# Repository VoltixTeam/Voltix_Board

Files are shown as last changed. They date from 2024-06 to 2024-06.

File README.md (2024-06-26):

# Voltix Board Hardware Design Files



The Voltix board is a development board for battery-free wireless devices. The on-board wireless microcontroller runs off energy harvested from, for example, a solar panel and uses only tiny capacitors as energy storage. For uploading new software, the board can be connected to a PC via USB. During sotware upload and debugging, the microcontroller is powered with a fixed supply voltage from USB. After programming, the board automatically switches over to untethered, battery-free operation.

Latest design files:
 - [Schematics](https://voltix-docs.vercel.app/artifacts/board/latest/schematics.pdf)
 - [Layout](https://voltix-docs.vercel.app/artifacts/board/latest/pcb.pdf)
 - [Assembly plan](https://voltix-docs.vercel.app/artifacts/board/latest/assembly.pdf)
 - [3D rendering](https://voltix-docs.vercel.app/artifacts/board/latest/3drendering.png)

## Specification

3D rendering

Essentially, the Voltix board combines a [Voltix probe](https://github.com/VoltixTeam/Voltix_ProbeHardware) and a Voltix module on a single board. The board has two 0.1" pin sockets that expose all relevant signals from the battery-free device, including 10 GPIOs that can be flexibly used for I2C, SPI or for reading analog sensors. These headers are also used to connect voltix shields to build fully featured devices without having to design custom PCBs. The board comes with a push button, an LED and a connector for a solar panel.

Specification:
 - 56mm x 23mm board with two expansion headers for shields
 - Boost converter with software-defined maximum power point tracking and energy measurement
 - 66uF on-board capacitance
 - 2V regulated output voltage
 - 64 MHz ARM Cortex-M4 MCU with integrated 2.4GHz radio
 - 128kB non-volatile FRAM to retain appliccation state across power outages
 - Ultra-low power RTC with power management functionality
 - Capacitor voltage sensing and ultra low power comparator with software-controlled thresholds
 - USB-C connector
 - CMSIS-DAP compatible: Supports programming via pyOCD and OpenOCD
 - Makes UART output from battery-free device available via USB
 - Push button and User LED

## Firmware

The board has a dedicated controller (Raspberry Pi RP2040) that manages the upload of new firmware and the communication with a PC. This controller is powered from USB whenever the board is connected to a PC. The software running on the controller is the same as on the [Voltix probe](https://github.com/VoltixTeam/Voltix_ProbeHardware) and can be found in [this repository](https://github.com/VoltixTeam/Voltix_ProbeSoftware). To upgrade the firmware on the controller, connect a wire from one of the ground pins to the test pad labelled 'USB_BOOT' on the bottom of the board, while plugging in the USB cable. A removable storage drive should appear on your PC. Drop a UF2 compatible binary into the drive.

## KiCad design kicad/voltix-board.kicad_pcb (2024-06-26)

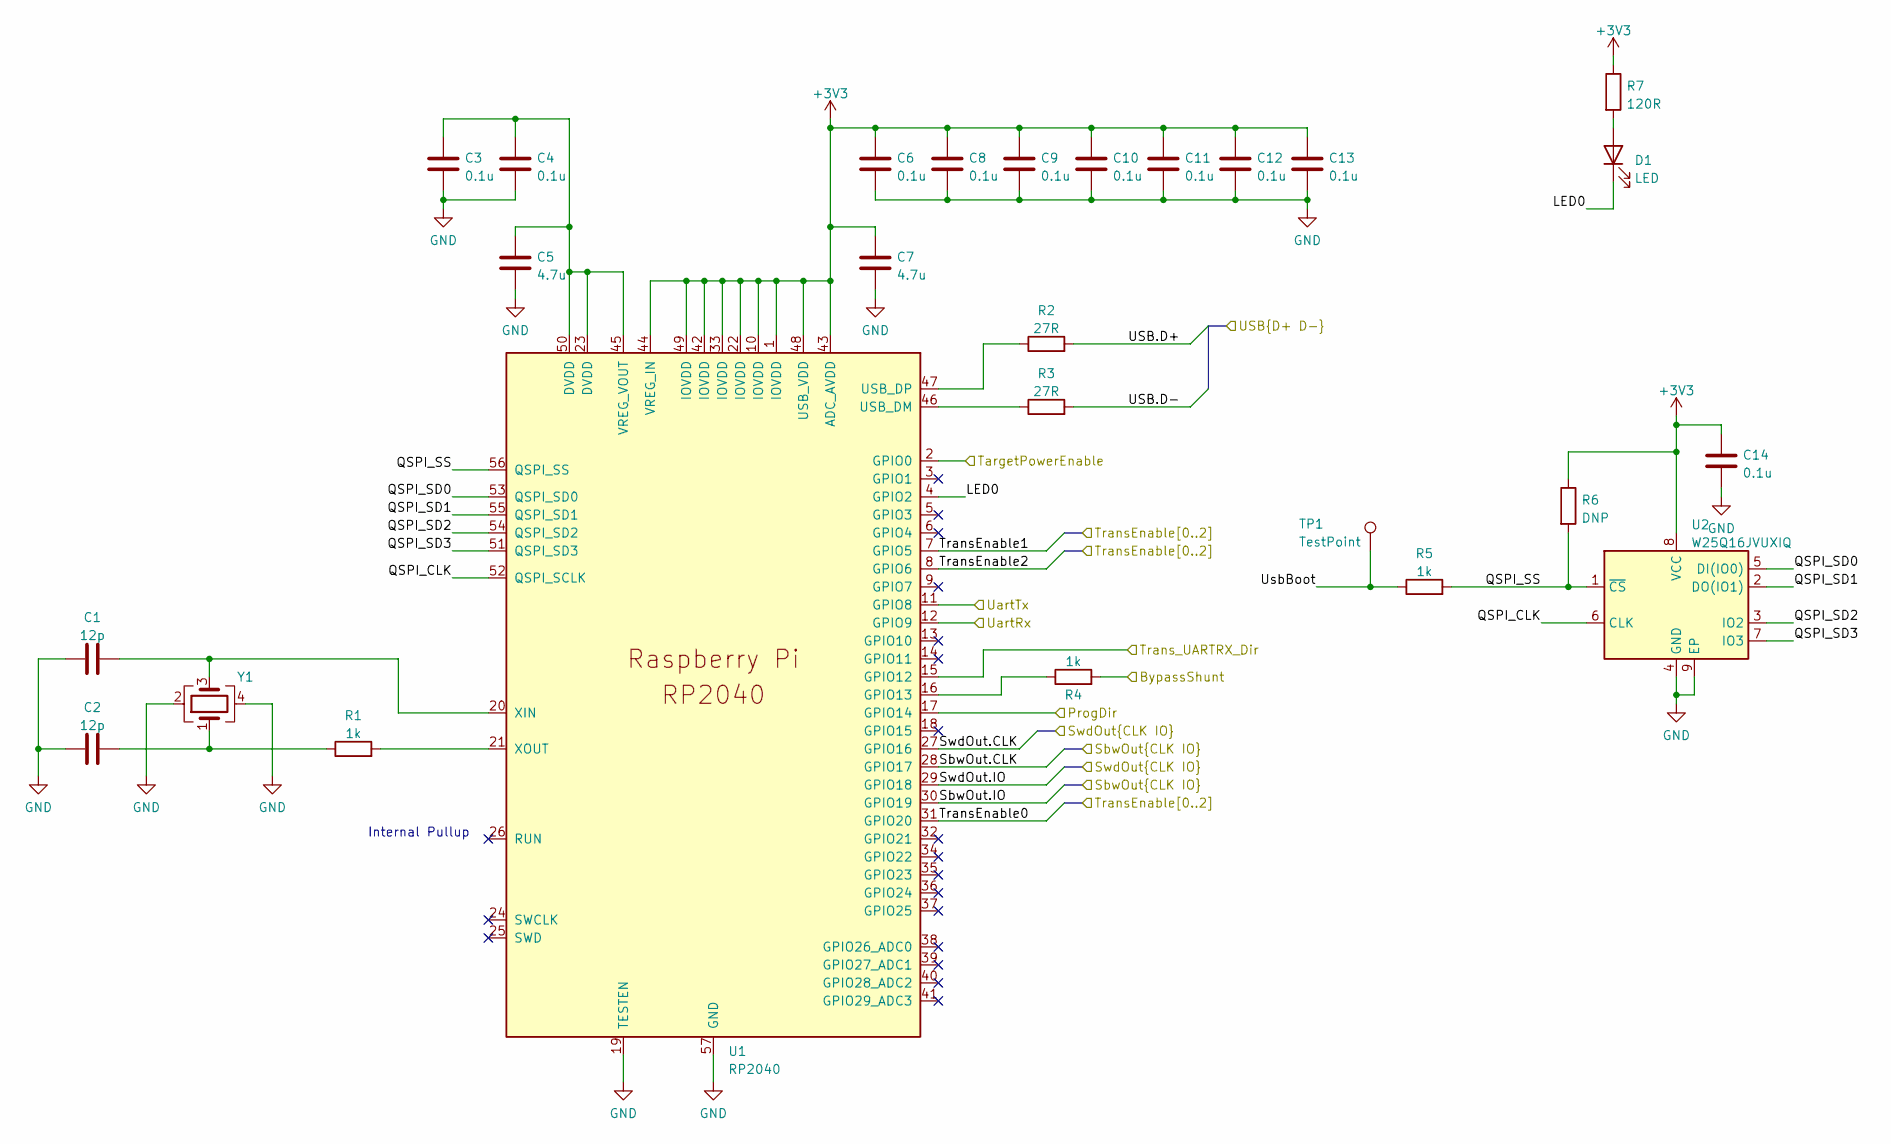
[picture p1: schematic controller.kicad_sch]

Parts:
C1, C2: 12p; C_0402_1005Metric; MPN 04025A120JAT2A
C3, C4, C6, C8, C9, C10, C11, C12, C13, C14: 0.1u; C_0402_1005Metric; MPN CL05A104KA5NNNC
C5, C7: 4.7u; C_0402_1005Metric; MPN CL05A475MP5NRNC
D1: LED; LED_0402_1005Metric; MPN QBLP595-AG1
R1, R4, R5: 1k; R_0402_1005Metric; MPN WR04X1001FTL
R2, R3: 27R; R_0402_1005Metric; MPN CR0402-FX-27R0GLF
R6: DNP; R_0402_1005Metric
R7: 120R; R_0402_1005Metric; MPN CR0402-FX-1200GLF
TP1: TestPoint; TestPoint_Pad_D1.0mm
U1: RP2040; RP_RP2040; MPN SC0914(13)
U2: W25Q16JVUXIQ; WB_UX8; MPN W25Q16JVUXIQ
Y1: Crystal_GND24; RALTRON_RH100; MPN RH100-12.000-18-2030-TR

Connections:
+3V3: C6.1, C7.1, C8.1, C9.1, C10.1, C11.1, C12.1, C13.1, C14.1, R6.1, R7.1, U1.1 (IOVDD), U1.10 (IOVDD), U1.22 (IOVDD), U1.33 (IOVDD), U1.42 (IOVDD), U1.43 (ADC_AVDD), U1.44 (VREG_IN), U1.48 (USB_VDD), U1.49 (IOVDD), U2.8 (VCC); also elsewhere on the board
/Controller/BypassShunt: R4.2; also elsewhere on the board
/Controller/LED0: D1.1 (K), U1.4 (GPIO2)
/Controller/ProgDir: U1.17 (GPIO14); also elsewhere on the board
/Controller/QSPI_CLK: U1.52 (QSPI_SCLK), U2.6 (CLK)
/Controller/QSPI_SD0: U1.53 (QSPI_SD0), U2.5 (DI(IO0))
/Controller/QSPI_SD1: U1.55 (QSPI_SD1), U2.2 (DO(IO1))
/Controller/QSPI_SD2: U1.54 (QSPI_SD2), U2.3 (IO2)
/Controller/QSPI_SD3: U1.51 (QSPI_SD3), U2.7 (IO3)
/Controller/QSPI_SS: R5.2, R6.2, U1.56 (QSPI_SS), U2.1 (~CS)
/Controller/SbwOut.CLK: U1.28 (GPIO17); also elsewhere on the board
/Controller/SbwOut.IO: U1.30 (GPIO19); also elsewhere on the board
/Controller/SwdOut.CLK: U1.27 (GPIO16); also elsewhere on the board
/Controller/SwdOut.IO: U1.29 (GPIO18); also elsewhere on the board
/Controller/TargetPowerEnable: U1.2 (GPIO0); also elsewhere on the board
/Controller/TransEnable0: U1.31 (GPIO20); also elsewhere on the board
/Controller/TransEnable1: U1.7 (GPIO5); also elsewhere on the board
/Controller/TransEnable2: U1.8 (GPIO6); also elsewhere on the board
/Controller/Trans_UARTRX_Dir: U1.15 (GPIO12); also elsewhere on the board
/Controller/USB.D+: R2.2; also elsewhere on the board
/Controller/USB.D-: R3.2; also elsewhere on the board
/Controller/UartRx: U1.12 (GPIO9); also elsewhere on the board
/Controller/UartTx: U1.11 (GPIO8); also elsewhere on the board
/Controller/UsbBoot: R5.1, TP1.1
GND: C1.1, C2.2, C3.2, C4.2, C5.2, C6.2, C7.2, C8.2, C9.2, C10.2, C11.2, C12.2, C13.2, C14.2, U1.19 (TESTEN), U1.57 (GND), U2.4 (GND), U2.9 (EP), Y1.2, Y1.4; also elsewhere on the board
unnamed: C2.1, R1.1, Y1.1
unnamed: D1.2 (A), R7.2
unnamed: R4.1, U1.16 (GPIO13)
unnamed: R3.1, U1.46 (USB_DM)
unnamed: R2.1, U1.47 (USB_DP)
unnamed: C3.1, C4.1, C5.1, U1.23 (DVDD), U1.45 (VREG_VOUT), U1.50 (DVDD)
unnamed: C1.2, U1.20 (XIN), Y1.3
unnamed: R1.2, U1.21 (XOUT)

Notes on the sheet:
Internal Pullup

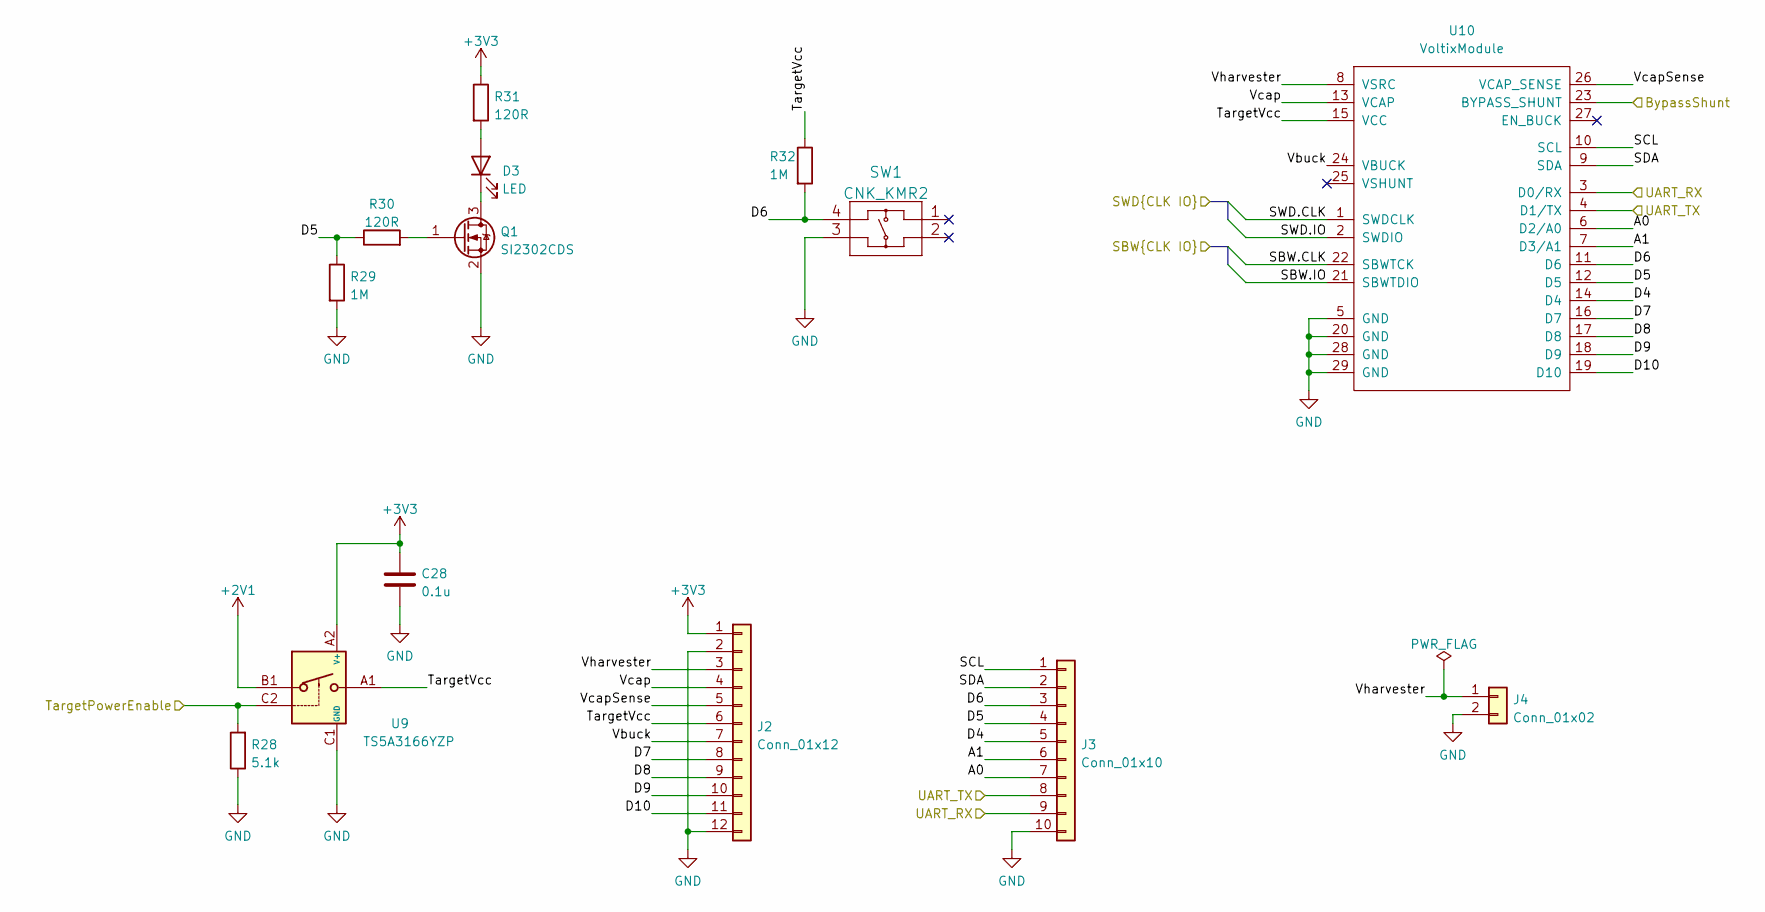
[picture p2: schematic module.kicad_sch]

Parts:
C28: 0.1u; C_0402_1005Metric; MPN CL05A104KA5NNNC
D3: LED; LED_0402_1005Metric; MPN QBLP595-AG1
J2: Conn_01x12; PinSocket_1x12_P2.54mm_Vertical; MPN PPPC121LFBN-RC
J3: Conn_01x10; PinSocket_1x10_P2.54mm_Vertical; MPN PPPC101LFBN-RC
J4: Conn_01x02; JST_S2B-PH-SM4-TB(LF)(SN); MPN 620102131822
Q1: SI2302CDS; VSH_SOT-23-3; MPN SI2302CDS-T1-GE3
R28: 5.1k; R_0402_1005Metric; MPN CR0402-FX-5101GLF
R29, R32: 1M; R_0402_1005Metric; MPN WR04X1004FTL
R30, R31: 120R; R_0402_1005Metric; MPN CR0402-FX-1200GLF
SW1: CNK_KMR2; CNK_KMR2_SW; MPN KMR221NG LFS
U9: TS5A3166YZP; TI_YZP0005; MPN TS5A3166YZP
U10: VoltixModule; NC_VoltixModule

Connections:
+2V1: U9.B1; also elsewhere on the board
+3V3: C28.1, J2.1, R31.1, U9.A2 (V+); also elsewhere on the board
/Controller/BypassShunt: U10.23 (BYPASS_SHUNT); also elsewhere on the board
/Controller/TargetPowerEnable: R28.2, U9.C2; also elsewhere on the board
/LevelShifter/Target_SBW.CLK: U10.22 (SBWTCK); also elsewhere on the board
/LevelShifter/Target_SBW.IO: U10.21 (SBWTDIO); also elsewhere on the board
/LevelShifter/Target_SWD.CLK: U10.1 (SWDCLK); also elsewhere on the board
/LevelShifter/Target_SWD.IO: U10.2 (SWDIO); also elsewhere on the board
/LevelShifter/Target_UART_RX: J3.9, U10.3 (D0/RX); also elsewhere on the board
/LevelShifter/Target_UART_TX: J3.8, U10.4 (D1/TX); also elsewhere on the board
/Voltix Module/A0: J3.7, U10.6 (D2/A0)
/Voltix Module/A1: J3.6, U10.7 (D3/A1)
/Voltix Module/D4: J3.5, U10.14 (D4)
/Voltix Module/D5: J3.4, R29.1, R30.1, U10.12 (D5)
/Voltix Module/D6: J3.3, R32.2, SW1.4, U10.11 (D6)
/Voltix Module/D7: J2.8, U10.16 (D7)
/Voltix Module/D8: J2.9, U10.17 (D8)
/Voltix Module/D9: J2.10, U10.18 (D9)
/Voltix Module/D10: J2.11, U10.19 (D10)
/Voltix Module/SCL: J3.1, U10.10 (SCL)
/Voltix Module/SDA: J3.2, U10.9 (SDA)
/Voltix Module/TargetVcc: J2.6, R32.1, U9.A1, U10.15 (VCC)
/Voltix Module/Vbuck: J2.7, U10.24 (VBUCK)
/Voltix Module/Vcap: J2.4, U10.13 (VCAP)
/Voltix Module/VcapSense: J2.5, U10.26 (VCAP_SENSE)
/Voltix Module/Vharvester: J2.3, J4.1, U10.8 (VSRC)
GND: C28.2, J2.2, J2.12, J3.10, J4.2, Q1.2 (S), R28.1, R29.2, SW1.3, U9.C1 (GND), U10.5 (GND), U10.20 (GND), U10.28 (GND), U10.29 (GND); also elsewhere on the board
unnamed: D3.2 (A), R31.2
unnamed: D3.1 (K), Q1.3 (D)
unnamed: Q1.1 (G), R30.2

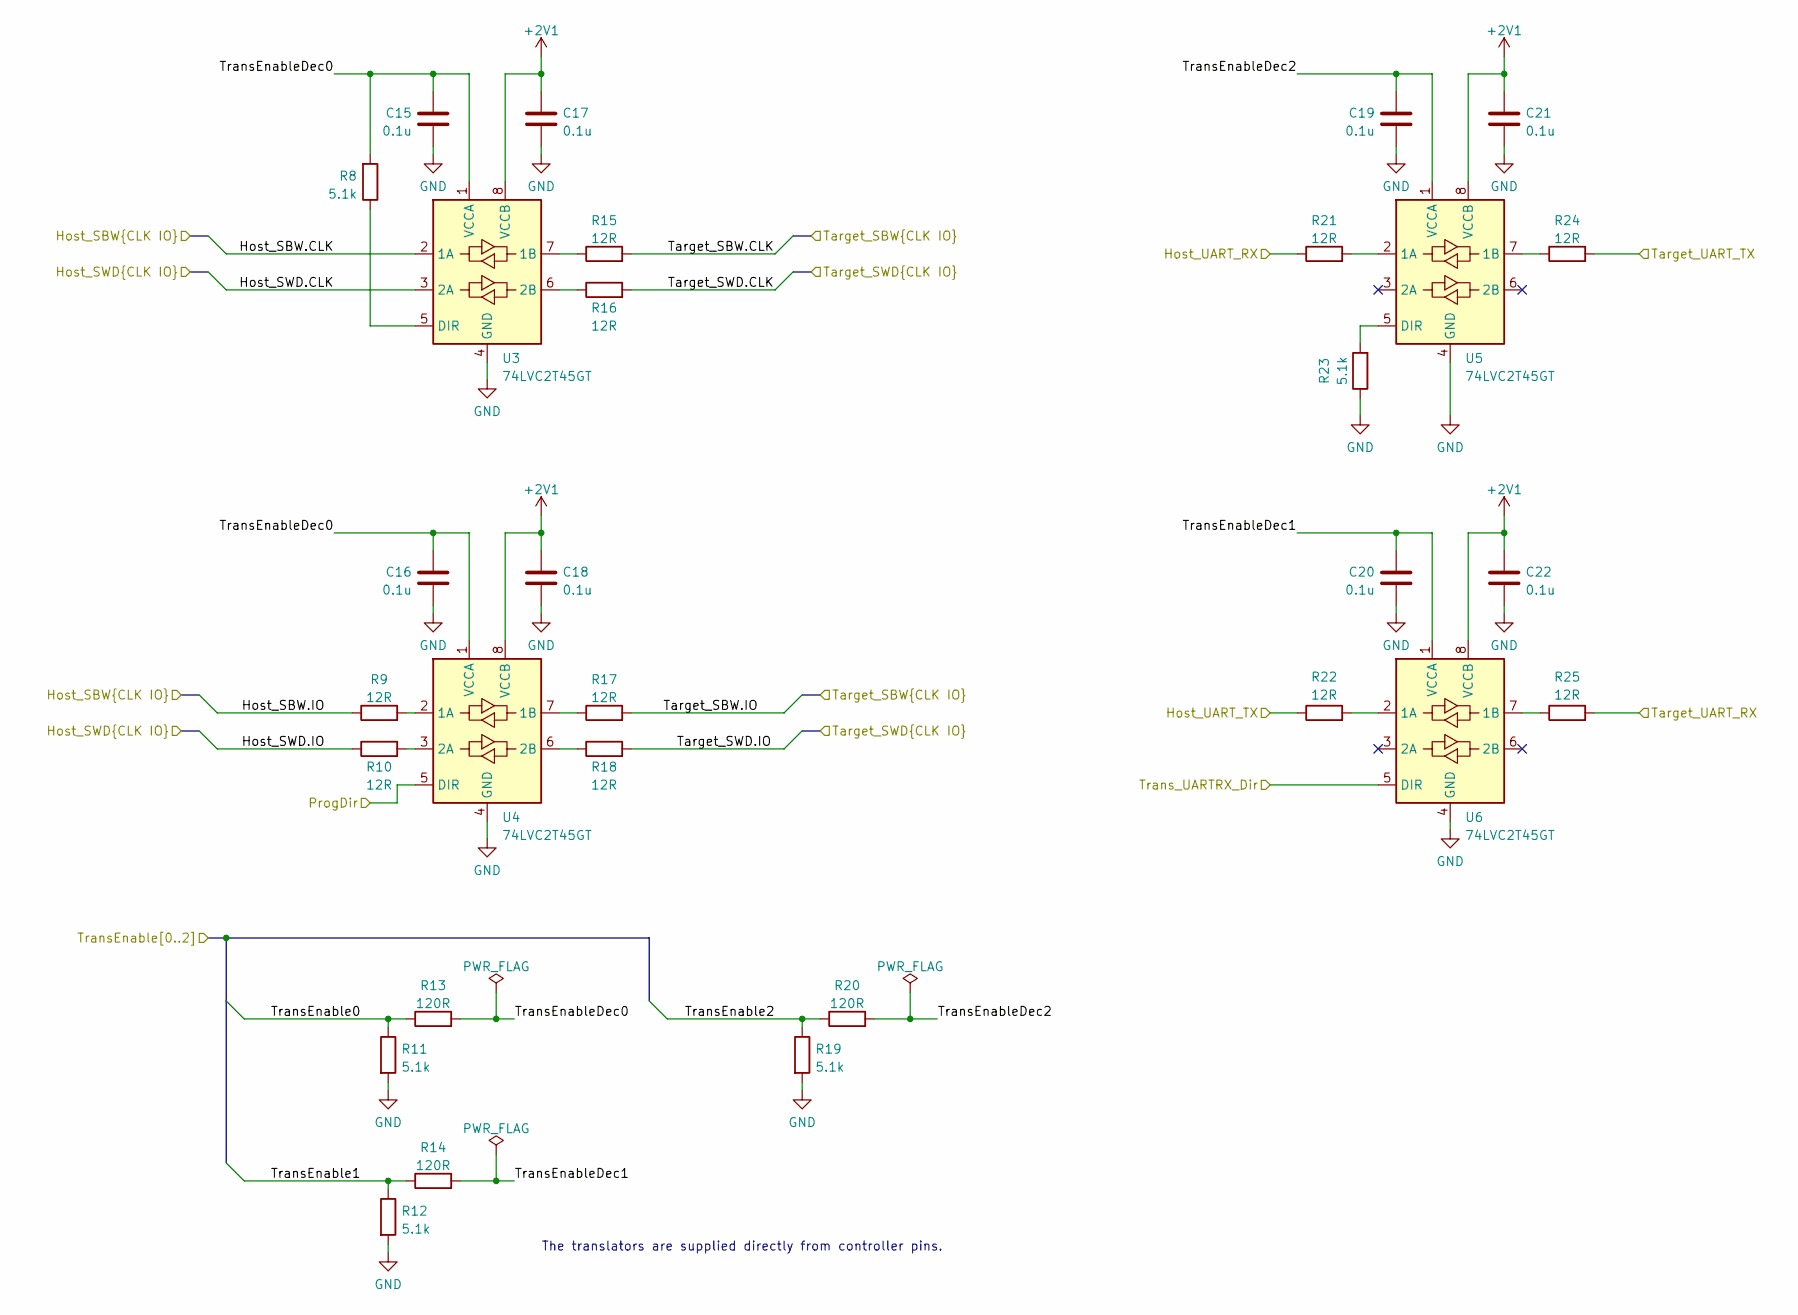
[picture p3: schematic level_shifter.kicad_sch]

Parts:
C15, C16, C17, C18, C19, C20, C21, C22: 0.1u; C_0402_1005Metric; MPN CL05A104KA5NNNC
R8, R11, R12, R19, R23: 5.1k; R_0402_1005Metric; MPN CR0402-FX-5101GLF
R9, R10, R15, R16, R17, R18, R21, R22, R24, R25: 12R; R_0402_1005Metric; MPN RMCF0402FT12R0
R13, R14, R20: 120R; R_0402_1005Metric; MPN CR0402-FX-1200GLF
U3, U4, U5, U6: 74LVC2T45GT; NXP_SOT833-1; MPN 74LVC2T45GT,115

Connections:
+2V1: C17.1, C18.1, C21.1, C22.1, U3.8 (VCCB), U4.8 (VCCB), U5.8 (VCCB), U6.8 (VCCB); also elsewhere on the board
/Controller/ProgDir: U4.5 (DIR); also elsewhere on the board
/Controller/SbwOut.CLK: U3.2 (1A); also elsewhere on the board
/Controller/SbwOut.IO: R9.1; also elsewhere on the board
/Controller/SwdOut.CLK: U3.3 (2A); also elsewhere on the board
/Controller/SwdOut.IO: R10.1; also elsewhere on the board
/Controller/TransEnable0: R11.1, R13.1; also elsewhere on the board
/Controller/TransEnable1: R12.1, R14.1; also elsewhere on the board
/Controller/TransEnable2: R19.1, R20.1; also elsewhere on the board
/Controller/Trans_UARTRX_Dir: U6.5 (DIR); also elsewhere on the board
/Controller/UartRx: R21.1; also elsewhere on the board
/Controller/UartTx: R22.1; also elsewhere on the board
/LevelShifter/Target_SBW.CLK: R15.2; also elsewhere on the board
/LevelShifter/Target_SBW.IO: R17.2; also elsewhere on the board
/LevelShifter/Target_SWD.CLK: R16.2; also elsewhere on the board
/LevelShifter/Target_SWD.IO: R18.2; also elsewhere on the board
/LevelShifter/Target_UART_RX: R25.2; also elsewhere on the board
/LevelShifter/Target_UART_TX: R24.2; also elsewhere on the board
/LevelShifter/TransEnableDec0: C15.2, C16.2, R8.2, R13.2, U3.1 (VCCA), U4.1 (VCCA)
/LevelShifter/TransEnableDec1: C20.2, R14.2, U6.1 (VCCA)
/LevelShifter/TransEnableDec2: C19.2, R20.2, U5.1 (VCCA)
GND: C15.1, C16.1, C17.2, C18.2, C19.1, C20.1, C21.2, C22.2, R11.2, R12.2, R19.2, R23.1, U3.4 (GND), U4.4 (GND), U5.4 (GND), U6.4 (GND); also elsewhere on the board
unnamed: R15.1, U3.7 (1B)
unnamed: R16.1, U3.6 (2B)
unnamed: R8.1, U3.5 (DIR)
unnamed: R9.2, U4.2 (1A)
unnamed: R17.1, U4.7 (1B)
unnamed: R10.2, U4.3 (2A)
unnamed: R18.1, U4.6 (2B)
unnamed: R21.2, U5.2 (1A)
unnamed: R24.1, U5.7 (1B)
unnamed: R23.2, U5.5 (DIR)
unnamed: R22.2, U6.2 (1A)
unnamed: R25.1, U6.7 (1B)

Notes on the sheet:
The translators are supplied directly from controller pins.

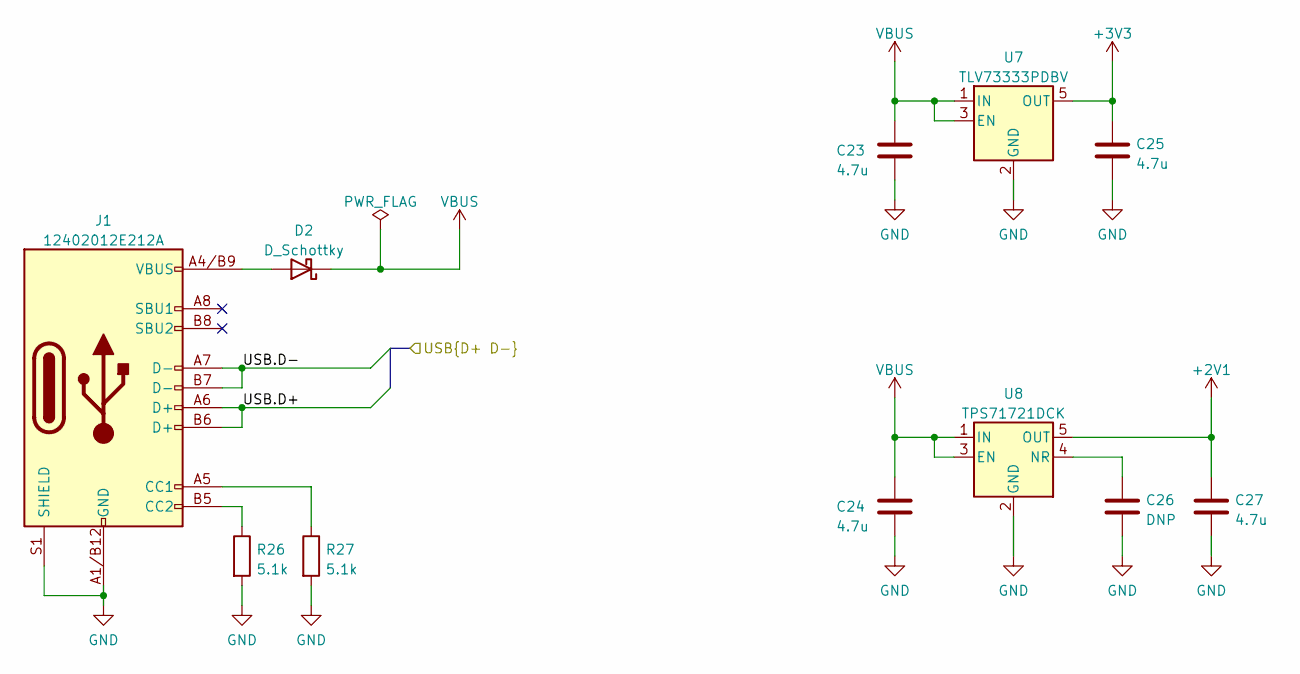
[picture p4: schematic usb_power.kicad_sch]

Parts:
C23, C24, C25, C27: 4.7u; C_0402_1005Metric; MPN CL05A475MP5NRNC
C26: DNP; C_0402_1005Metric
D2: D_Schottky; D_SOD-523; MPN RB521S30T1G
J1: 12402012E212A; AMPH_12402012E212A; MPN 12402012E212A
R26, R27: 5.1k; R_0402_1005Metric; MPN CR0402-FX-5101GLF
U7: TLV73333PDBV; TI_DBV0005A; MPN TLV73333PDBV
U8: TPS71721DCK; TI_DCK0005A; MPN TPS71721DCK

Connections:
+2V1: C27.1, U8.5 (OUT); also elsewhere on the board
+3V3: C25.1, U7.5 (OUT); also elsewhere on the board
/Controller/USB.D+: J1.A6 (D+), J1.B6 (D+); also elsewhere on the board
/Controller/USB.D-: J1.A7 (D-), J1.B7 (D-); also elsewhere on the board
GND: C23.2, C24.2, C25.2, C26.2, C27.2, J1.A1/B12 (GND), J1.B1/A12 (GND), J1.S1 (SHIELD), R26.2, R27.2, U7.2 (GND), U8.2 (GND); also elsewhere on the board
unnamed: D2.2 (A), J1.A4/B9 (VBUS), J1.B4/A9 (VBUS)
unnamed: J1.A5 (CC1), R27.1
unnamed: J1.B5 (CC2), R26.1
unnamed: C26.1, U8.4 (NR)
VBUS: C23.1, C24.1, D2.1 (K), U7.1 (IN), U7.3 (EN), U8.1 (IN), U8.3 (EN)

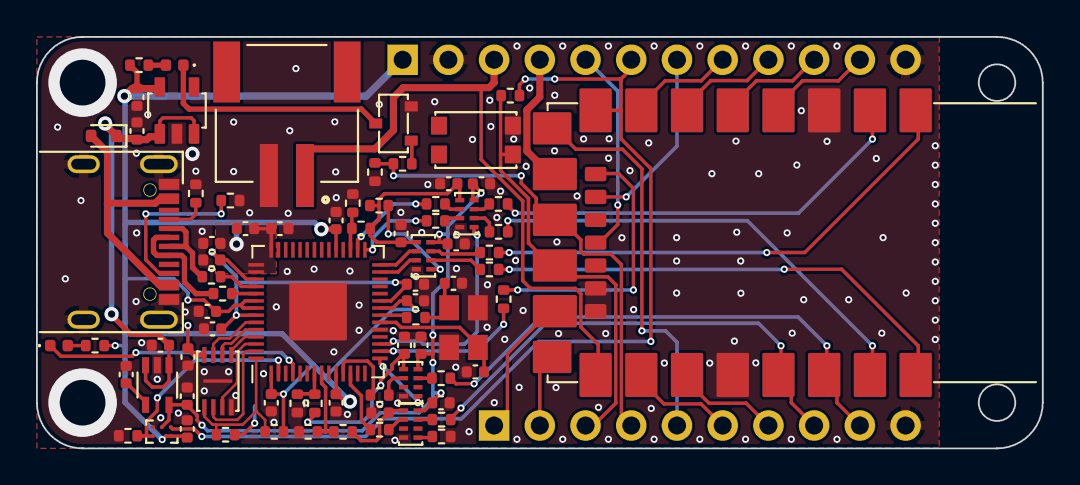
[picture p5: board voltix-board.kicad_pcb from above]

Board: 4 copper layers, 55.9 x 22.9 mm, 81 parts (1 on the bottom side), 79 nets.
